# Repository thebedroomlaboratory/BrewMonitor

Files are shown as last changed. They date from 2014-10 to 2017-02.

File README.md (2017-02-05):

# BrewMonitor

## The Arduino and Cloud-based homebrewing controller

Homepage: http://thebedlab.com/brewmonitor-the-arduino-and-cloud-based-homebrewing-controller/

Demo sites:

* http://dev.thebedlab.com/~martin/brewmonitor/ (PHP - Stable)
* http://dev.thebedlab.com/brewmonitor/ (Node - Unstable)

### Arduino Library Requirements (latest versions):

* http://www.pjrc.com/teensy/td_libs_OneWire.html
* http://milesburton.com/Main_Page?title=Dallas_Temperature_Control_Library

### REST API Format

* PHP Backend
  * http://dev.thebedlab.com/~martin/brewmonitor/api/help (to be added but this is a placeholder)
  * http://dev.thebedlab.com/~martin/brewmonitor/api/readings (GET)
  * http://dev.thebedlab.com/~martin/brewmonitor/api/readings (POST)
    * as URL parameters
    * `http://dev.thebedlab.com/~martin/brewmonitor/api/readings/?device=1&temp=20.0&heaton=1.0`
* Node.js Backend
  * http://dev.thebedlab.com/brewmonitor/api/v1.0/help
  * http://dev.thebedlab.com/brewmonitor/api/v1.0/list (GET)
    * URL parameters optional, e.g.
    * http://dev.thebedlab.com/brewmonitor/api/v1.0/list?devid=1&userid=1
  * http://dev.thebedlab.com/brewmonitor/api/v1.0 (POST)
    * `{ "userid": 0, "devid": 0, "temps": [{"sensid": 0, "temp": 20.2}, {"sensid": 1, "temp": 20.8}], "timestamp": "2014-11-15T16:56:08.506Z" }`

### Installation

First thing to do is to clone this repository. All paths are given relative to the root of the repository. From here on it is also assumed that the root of the repository will show up at http://domain/

#### Stable Version (PHP/MySQL Backend with Angular on frontend)

* Install apache2 mysql php5 php5-mcrypt php5-apache2 php5-zip php5-mysql php5-pdo-mysql phpmyadmin composer
* `composer self-update`
* `composer global require "laravel/installer=~1.1"`
* add ~/.composer/vendor/bin to $PATH in .bash_profile
* `cd Backend`
* `wget https://github.com/laravel/laravel/archive/master.zip`
* `rm -r laravel`
* `unzip master.zip`
* `mv laravel-master laravel`
* `cd laravel`
* `git checkout .`
* `composer install`
* `cd ../../Frontend/brewmonitor/js`
* `mkdir graphing`
* `cd graphing`
* `wget http://dev.thebedlab.com/~martin/brewmonitor/js/graphing/angular-moment.min.js; wget http://dev.thebedlab.com/~martin/brewmonitor/js/graphing/angular-moment.min.js.map; wget http://dev.thebedlab.com/~martin/brewmonitor/js/graphing/line-chart.min.js; wget http://dev.thebedlab.com/~martin/brewmonitor/js/graphing/moment.min.js`
* Configure your username/password settings in `Backend/laravel/app/config/database.php`
* Create database table and seed it with some sample data
  * Use phpmyadmin to create table called `brewmonitor`
  * `cd Backend/laravel`
  * `php artisan migrate`
  * `php artisan db:seed`
* That's it! You should now be able to see a graph in your browser at http://domain/Frontend/brewmonitor/ once apache2 and mysql are running

#### Development Version (Node.js/MongoDB Backend)

##### MongoDB

Make sure Mongo is installed and running. A dump of the DB was created in `Backend` using:
```bash
cd Backend
mongodump -d brew
```
This can be loaded locally using:
```bash
cd Backend
mongorestore
```

##### Node-Red

Download and extract node-red zip file from http://nodered.org/ to `Backend/node-red`
```bash
cd Backend/node-red
npm install --production
npm install mongodb
rm settings.js
ln -s ../settings.js
```
If you have any complications or want to install Additional Nodes, check the instructions on http://nodered.org/docs/getting-started/installation.html

##### Apache2 and Node-Red at same time

Configure Apache with the following settings:
```bash
LoadModule proxy_module modules/mod_proxy.so
LoadModule proxy_http_module modules/mod_proxy_http.so
LoadModule proxy_wstunnel_module modules/mod_proxy_wstunnel.so

ProxyPreserveHost On
ProxyRequests Off
ProxyPass /brewmonitor/comms ws://127.0.0.1:8123/brewmonitor/comms
ProxyPass /brewmonitor http://127.0.0.1:8123/brewmonitor
ProxyPassReverse /brewmonitor http://127.0.0.1:8123/brewmonitor
```
You can do this using:

* `a2enmod` and `/etc/apache2/sites-enabled/000-default.conf` (Ubuntu)
* Or all in your `httpd.conf` file by adding the text as above (codio.com)
* Either way, remember to restart Apache afterwards so that the settings can take effect
 
After that, check that your node-red app/server settings match up. This can be found in `Backend/settings.js`:

* `uiPort: 8123,`
* `httpRoot: '/brewmonitor',`

You may as well allow AJAX calls from other servers at this point too, if required (Ionic app for instance...)
```bash
 httpNodeCors: {
  origin: "*",
  methods: "GET,PUT,POST,DELETE"
 },
```

##### Running Server
Make sure MongoDB and Apache are running, then run the following command:
```bash
./startNodeRed.sh
```
This launches the Node-Red server which can then be found at http://domain/brewmonitor/. To run it as a daemon, do the following (sudo may be required for global npm install):
```bash
cd Backend/node-red
npm install forever -g
forever start red.js ../BrewMonitor.json
```

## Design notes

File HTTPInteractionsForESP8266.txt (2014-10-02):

AT+RST\r\n
AT+CWJAP="SSID","PASSWORD"\r\n
AT+CIPSTART="TCP","54.76.114.101",80\r\n
AT+CIPSEND=86\r\n
GET /~martin/brewmonitor/api/readings HTTP/1.0\r\nHost: dev.thebedroomlaboratory.com\r\n\r\n
AT+CIPSEND=201\r\n
POST /~martin/brewmonitor/api/readings HTTP/1.0\r\nHost: dev.thebedroomlaboratory.com\r\nCache-Control: no-cache\r\nContent-Type: application/x-www-form-urlencoded\r\nContent-Length: 18\r\n\r\ndevice=1&temp=18.6\r\n

AT+CIPSTART="TCP","54.76.114.101",80

OK
Linked
AT+CIPSEND=201

> POST /~martin/brewmonitor/api/readings HTTP/1.0
Host: dev.thebedroomlaboratory.com
Cache-Control: no-cache
Content-Type: application/x-www-form-urlencoded
Content-Length: 18

device=1&temp=18.6

SEND OK

+IPD,643:HTTP/1.0 200 OK
Date: Wed, 01 Oct 2014 15:32:51 GMT
Server: Apache/2.4.7 (Ubuntu)
X-Powered-By: PHP/5.5.9-1ubuntu4.4
Cache-Control: private, must-revalidate
pragma: no-cache
expires: -1
Set-Cookie: laravel_session=eyJpdiI6Inp2REhPdTJVanZJT01Udk1xbUJUM1E9PSIsInZhbHVlIjoiRHhibU5lUW5pcHllRVNzalhqOEhSdDZaQ2x6QVp4UVRBQzVzZEMrU0ZCd2RzRVk0SHBFZCtMem9keE1QQ2h5dlFBWFJha3E4T3QwTTFONVVoWTAzdVE9PSIsIm1hYyI6ImJkYTBhNzI2YTNiNDY2ZTM2ZGI3NmM3MTliODBiZmQ1ZjAwYzk3MzY2ZWYwOGVhM2I2YjVlZDRlMjg3ZmYyMDIifQ%3D%3D; expires=Wed, 01-Oct-2014 17:32:52 GMT; Max-Age=7200; path=/; httponly
Connection: close
Content-Type: application/json

{"success":true}
OK

OK
Unlink

AT+CIPSTART="TCP","54.76.114.101",80

OK
Linked
AT+CIPSEND=86

> GET /~martin/brewmonitor/api/readings HTTP/1.0
Host: dev.thebedroomlaboratory.com

SEND OK

+IPD,1024:HTTP/1.0 200 OK
Date: Wed, 01 Oct 2014 16:05:27 GMT
Server: Apache/2.4.7 (Ubuntu)
X-Powered-By: PHP/5.5.9-1ubuntu4.4
Cache-Control: private, must-revalidate
pragma: no-cache
expires: -1
Set-Cookie: laravel_session=eyJpdiI6ImlNRkVUTkRUSVZzVU1sU1VuRDQxRGc9PSIsInZhbHVlIjoiUjFVSGxLeHc5UjllaEt5VDBkRzRsekx3U0J5eERYWFwvbkxzU2tkZGwxUlFZNTZJVWwzN0ViVUpkXC9YYjRzRkhBTWIrTEVQcWJDb2htak1UdGhac0RMQT09IiwibWFjIjoiZDJhODk3YTVhMzRhOWYyMGI5YWY2ZGI1YzljY2Y2ODcwMmE2ZTkwMzlkN2I1ZTNlYWFkNWNlZjMwYWIxMDA3MSJ9; expires=Wed, 01-Oct-2014 18:05:27 GMT; Max-Age=7200; path=/; httponly
Connection: close
Content-Type: application/json

[{"id":"1","device":"1","temp":"20.50","created_at":"2014-09-30 12:34:00","updated_at":"2014-09-30 12:34:39"},{"id":"2","device":"1","temp":"20.70","created_at":"2014-09-30 12:35:00","updated_at":"2014-09-30 12:34:39"},{"id":"3","device":"1","temp":"21.00","created_at":"2014-09-30 12:36:00","updated_at":"2014-09-30 12:34:40"},{"id":"4","device":"1","temp":"22.00","created_at":"2014-09-30 16:31:26",
OK

+IPD,363:"updated_at":"2014-09-30 16:31:26"},{"id":"5","device":"1","temp":"17.10","created_at":"2014-10-01 12:40:26","updated_at":"2014-10-01 12:40:26"},{"id":"6","device":"1","temp":"17.10","created_at":"2014-10-01 13:40:11","updated_at":"2014-10-01 13:40:11"},{"id":"7","device":"1","temp":"18.60","created_at":"2014-10-01 15:32:52","updated_at":"2014-10-01 15:32:52"}]
OK

OK
Unlink

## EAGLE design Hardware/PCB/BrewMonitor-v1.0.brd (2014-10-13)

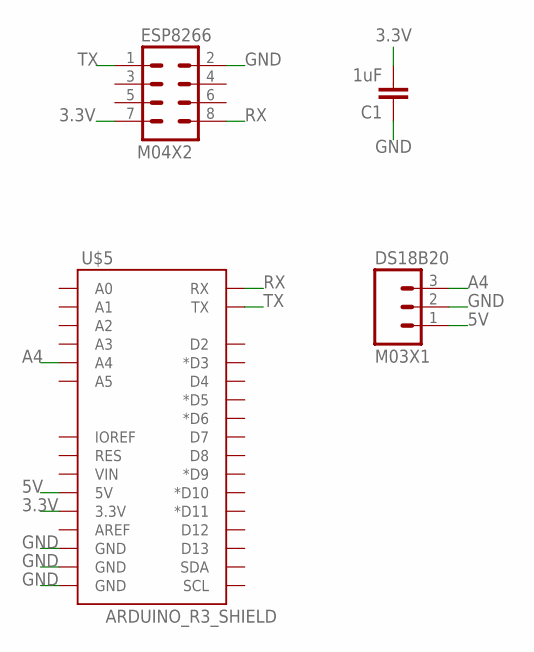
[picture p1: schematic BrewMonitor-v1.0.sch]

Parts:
C1: 1uF; CAP-PTH-SMALL
DS18B20: M03X1; SCREWTERMINAL-3.5MM-3
ESP8266: M04X2; 2X4
U$5: ARDUINO_R3_SHIELD; UNO_R3_SHIELD

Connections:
3.3V: C1.2, ESP8266.7, U$5.3.3V
5V: DS18B20.1, U$5.5V
A4: DS18B20.3, U$5.A4
GND: C1.1, DS18B20.2, ESP8266.2, U$5.GND@0 (GND), U$5.GND@1 (GND), U$5.GND@2 (GND)
RX: ESP8266.8, U$5.RX
TX: ESP8266.1, U$5.TX

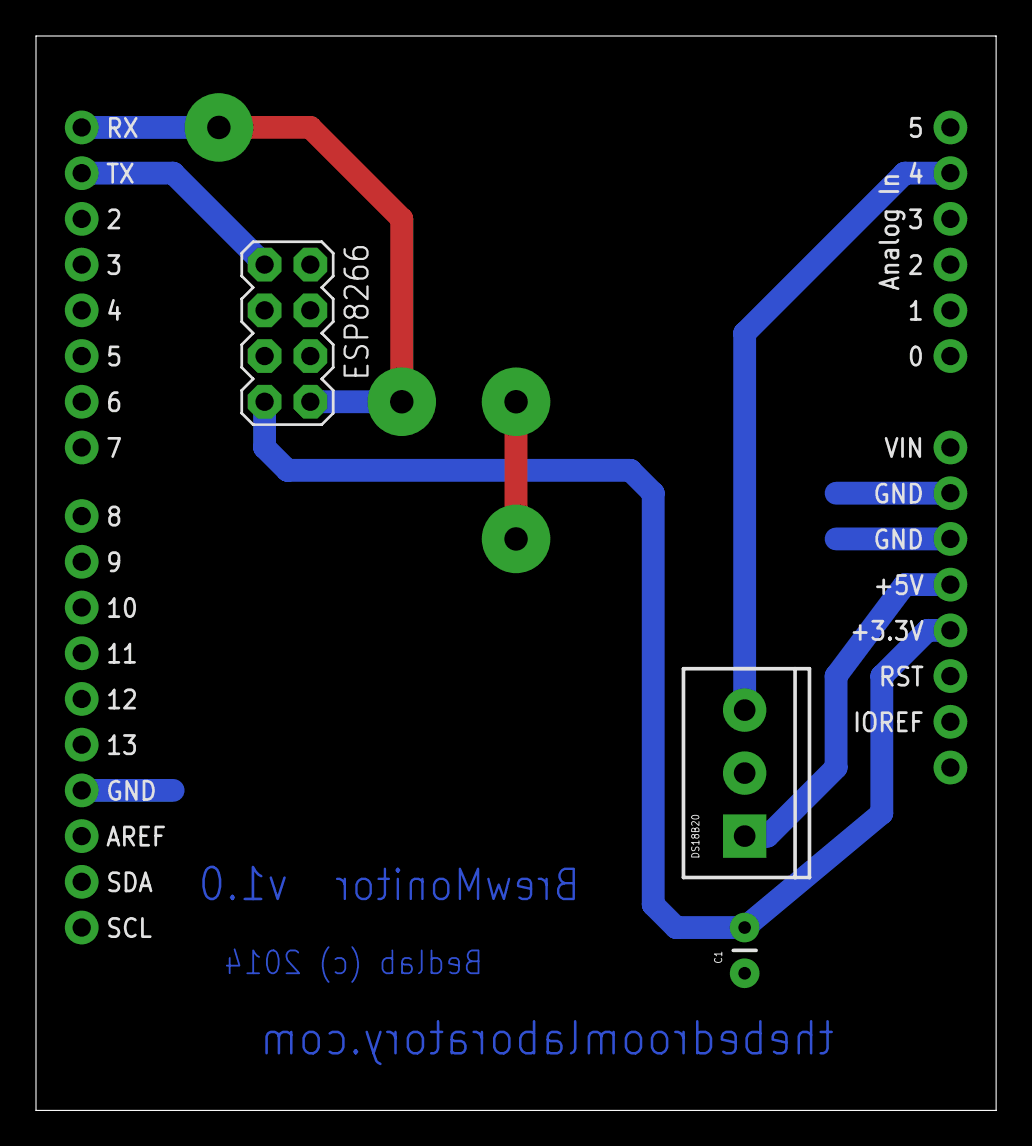
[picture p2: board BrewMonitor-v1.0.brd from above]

Board: 2 copper layers, 53.3 x 59.7 mm, 4 parts (0 on the bottom side), 6 nets.

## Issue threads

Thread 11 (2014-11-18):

Replace long delays with millis check

matsstaff, 2014-11-18:
In main loop, it would be better to use the standard if(last-millis() > xxx) instead of long delays.

catchmartin, 2015-01-19:
Done (126c47cebe8a2ec2aa0c8265d4ecca41ffdaa14c). Arduino sketch still a work in progress though.

Closed 2015-01-19.

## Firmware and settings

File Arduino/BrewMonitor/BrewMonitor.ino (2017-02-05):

#include <OneWire.h>
#include <DallasTemperature.h>
#include <SoftwareSerial.h>

// Data wire is plugged into pin A4 on the Arduino
#define ONE_WIRE_BUS A0
SoftwareSerial mySerial(4, 5); // RX, TX
#define SSID "SSID"
#define PASS "PASSWORD"
#define DST_IP "52.50.20.110" // dev.thebedlab.com
#define PATH "/~martin/brewmonitor/api/readings"
#define HOST "dev.thebedlab.com"
#define DEV_ID "2" //can be used in future developments for multiple installations
unsigned long transmissionFrequency = 30000;
unsigned long checkFrequency = 5000;
double Setpoint = 19.5;

// Setup a oneWire instance to communicate with any OneWire devices
// (not just Maxim/Dallas temperature ICs)
OneWire oneWire(ONE_WIRE_BUS);
// Pass our oneWire reference to Dallas Temperature.
DallasTemperature sensors(&oneWire);
unsigned long lastTransmission, lastCheck;
boolean webConnected;
int RelayPin = 12;
int RelayPower = 2;
boolean heatingOn = false;

void setup()
{
  pinMode(RelayPin, OUTPUT);
  pinMode(RelayPower, OUTPUT);
  digitalWrite(RelayPin, HIGH);
  digitalWrite(RelayPower, HIGH);
  webConnected = false;
  mySerial.begin(9600);
  pinMode(13, OUTPUT);
  digitalWrite(13, LOW);
  lastTransmission = millis();
  lastCheck = millis();
  Serial.begin(9600);
  while (!Serial) {
    ; // wait for serial port to connect. Needed for Leonardo only
  }
  for (int i = 0; i < 10; i++)
  {
    if (!webConnected) {
      mySerial.println("AT");
      //delay(1000);
      if (mySerial.find("OK"))
      {
        webConnected = true;
        Serial.println("Module is addressable");
        break;
      }
    }
  }
  if (!webConnected)
  {
    // Turn LED on continuously to signify stall
    ledOn();
    Serial.println("Module not addressable. Try resetting or continue without Internet.");
  }
  else {
    delay(1000);
    //connect to the wifi
    webConnected = false;
    for (int i = 0; i < 10; i++)
    {
      if (connectWiFi())
      {
        // flash LED to let us know that device connected
        flash();
        Serial.println("Module is connected to WLAN");
        webConnected = true;
        break;
      }
    }
    if (!webConnected)
    {
      // Turn LED on continuously to signify stall
      ledOn();
      Serial.println("Could not connect to WLAN. Try resetting or continue without Internet.");
    }
    delay(5000);
    Serial.println("AT+CIPMUX=0");
  }
  sensors.begin();
}

void loop()
{
  if (millis() - lastCheck > checkFrequency) {
    lastCheck = lastCheck + checkFrequency;
    sensors.requestTemperatures();
    float temperature = sensors.getTempCByIndex(0);
    if (!heatingOn && temperature < (Setpoint - 0.2))
    {
      heatingOn = true;
      Serial.println("Turning Heating On.");
      digitalWrite(RelayPin, LOW);
    }
    else if (heatingOn && temperature > Setpoint)
    {
      heatingOn = false;
      Serial.println("Turning Heating Off.");
      digitalWrite(RelayPin, HIGH);
    }

    Serial.print("HeatingOn=");
    Serial.print(heatingOn);
    Serial.print("Temp=");
    Serial.println(temperature);
  }


  if (webConnected && (millis() - lastTransmission > transmissionFrequency))
  {
    lastTransmission += transmissionFrequency;
    String cmd = "AT+CIPSTART=\"TCP\",\"";
    cmd += DST_IP;
    cmd += "\",80";
    mySerial.println(cmd);
    if (mySerial.find("Error")) return;
    sensors.requestTemperatures();
    float tempf = sensors.getTempCByIndex(0);
    int temp1 = (int)tempf;
    int temp2 = (tempf - temp1) * 100;
    String temp = "";
    temp += temp1;
    temp += ".";
    if (temp2 < 10)
      temp += "0";
    temp += temp2;
    String payload = "device=";
    payload += DEV_ID;
    payload += "&temp=" + temp;
    payload += "&heaton=";
    payload += heatingOn;
    Serial.println(payload);
    cmd = "POST ";
    cmd += PATH;
    cmd += " HTTP/1.0\r\nHost: ";
    cmd += HOST;
    cmd += "\r\nCache-Control: no-cache\r\nContent-Type: application/x-www-form-urlencoded\r\nContent-Length: ";
    cmd += payload.length();
    cmd += "\r\n\r\n";
    cmd += payload;
    cmd += "\r\n";
    mySerial.print("AT+CIPSEND=");
    mySerial.println(cmd.length());
    if (mySerial.find(">"))
    {
    } else
    {
      mySerial.println("AT+CIPCLOSE");
      delay(1000);
      return;
    }
    mySerial.print(cmd);
    // flash LED to let us know that msg sent
    flash();
    Serial.println("Successful upload.");
    delay(1000);
    while (mySerial.available())
    {
      char c = mySerial.read();
    }
  }
}

boolean connectWiFi()
{
  mySerial.println("AT+CWMODE=1");
  delay(2000);
  String cmd = "AT+CWJAP=\"";
  cmd += SSID;
  cmd += "\",\"";
  cmd += PASS;
  cmd += "\"";
  mySerial.println(cmd);
  delay(5000);
  if (mySerial.find("OK"))
  {
    Serial.println("Connected to AP");
    return true;
  } else
  {
    Serial.println("Not connected to AP");
    return false;
  }
}

void ledOn() {
  digitalWrite(13, HIGH);
}

void flash()
{
  digitalWrite(13, HIGH);
  delay(1000);
  digitalWrite(13, LOW);
}

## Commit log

2014-10-02 First commit of code/design files. The Arduino/BrewMonitor/BrewMonitor.ino sketch is working perfectly but could do with a bit of polishing and power-aware coding. The Eagle directory is currently on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
    [BrewMonitor-v1.0.brd, BrewMonitor-v1.0.sch]
2014-10-07 Edited arduino sketch to remove all software serial references. Changed the frequency of temperature posts to 30 mins. This reduces the likelihood of stalling in the javascript on the front end as a 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
    [BrewMonitor.ino]
2014-10-11 Updated Eagle Schematic for the correct parts and made net connections. The brd file still needs updating.
    [BrewMonitor-v1.0.brd, BrewMonitor-v1.0.sch]
2014-10-13 Updated Schematic and Board files. Circuit now complete.
    [BrewMonitor-v1.0.brd, BrewMonitor-v1.0.sch]
2014-10-13 Removed file for placeholder circuit.
2014-11-12 Tidying Hardware folder structure.
    [BrewMonitor-v1.0.brd, BrewMonitor-v1.0.sch]
2015-01-18 Updated code for first version of temperature controller with WiFi. Code needs to be tidied but is currently live on both the client and server and it's hooked up to two two different IPAs fermenting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
2015-01-26 Updated node-red app so that it doesn't print to console any more. Debug tab in browser is enough
2015-01-31 Updated README.md to reflect current API routes
2017-02-05 Updated endpoints and fermentation temperature

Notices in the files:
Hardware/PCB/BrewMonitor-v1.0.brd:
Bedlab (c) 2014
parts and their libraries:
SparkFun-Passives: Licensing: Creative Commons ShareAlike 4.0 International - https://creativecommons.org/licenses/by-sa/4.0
